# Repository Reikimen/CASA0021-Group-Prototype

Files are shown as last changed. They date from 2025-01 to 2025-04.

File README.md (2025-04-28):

# CASA0021: Group Prototype and Pitch 24/25

<div style="text-align: center;">
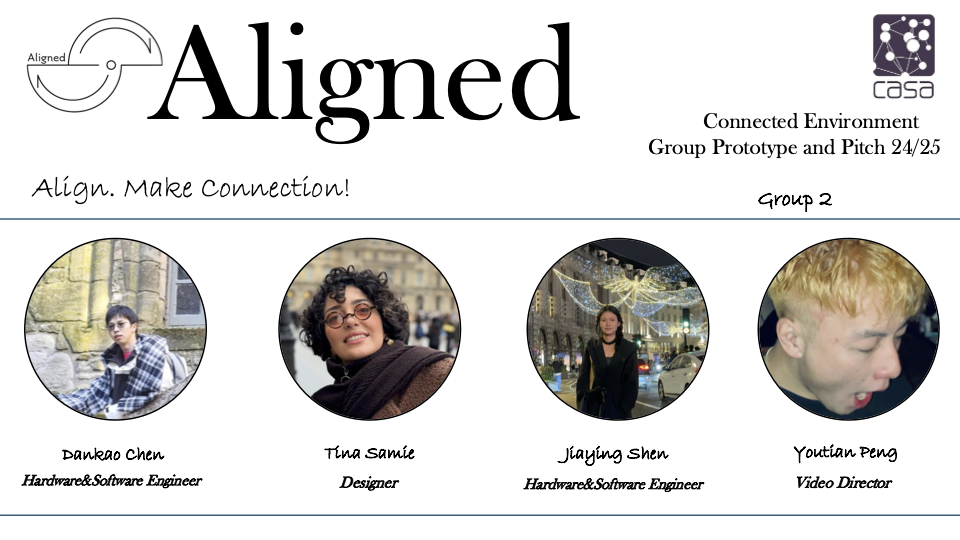
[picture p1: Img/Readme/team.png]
  
</div>

## 📌 Introduction

**Aligned** is a paired emotional communication device for people in long-distance relationships—whether romantic partners, family, or close friends. Instead of relying on texts or video calls, users connect by physically aligning their devices and sending emotions through light and vibration.

When one user rotates their device to face the direction of their partner and presses a button, a message is sent—but it will only be received when the other user also aligns in return. This two-way interaction adds a sense of presence and emotional balance that typical communication tools often lack.

**Aligned isn’t just a compass—it’s your emotional North Star.**

## 🌍 Why Aligned?

Staying connected across distances can be emotionally draining. Traditional tools like messaging and video calls are often screen-heavy, verbal, and fatiguing.

**Aligned** takes a different approach. It brings back the power of non-verbal connection—through direction, movement, and shared moments. Inspired by studies on the importance of physical cues in emotional bonding, Aligned helps users feel close, quietly and intentionally.

----

## 🎬 Demo Video

See how **Aligned** works in action:  
[▶️ Watch the short demo on YouTube](https://www.youtube.com/watch?v=aNNHWGniDm8)

---

## 🧭 How to Use Aligned

<table>
  <tr>
    <td align="center">
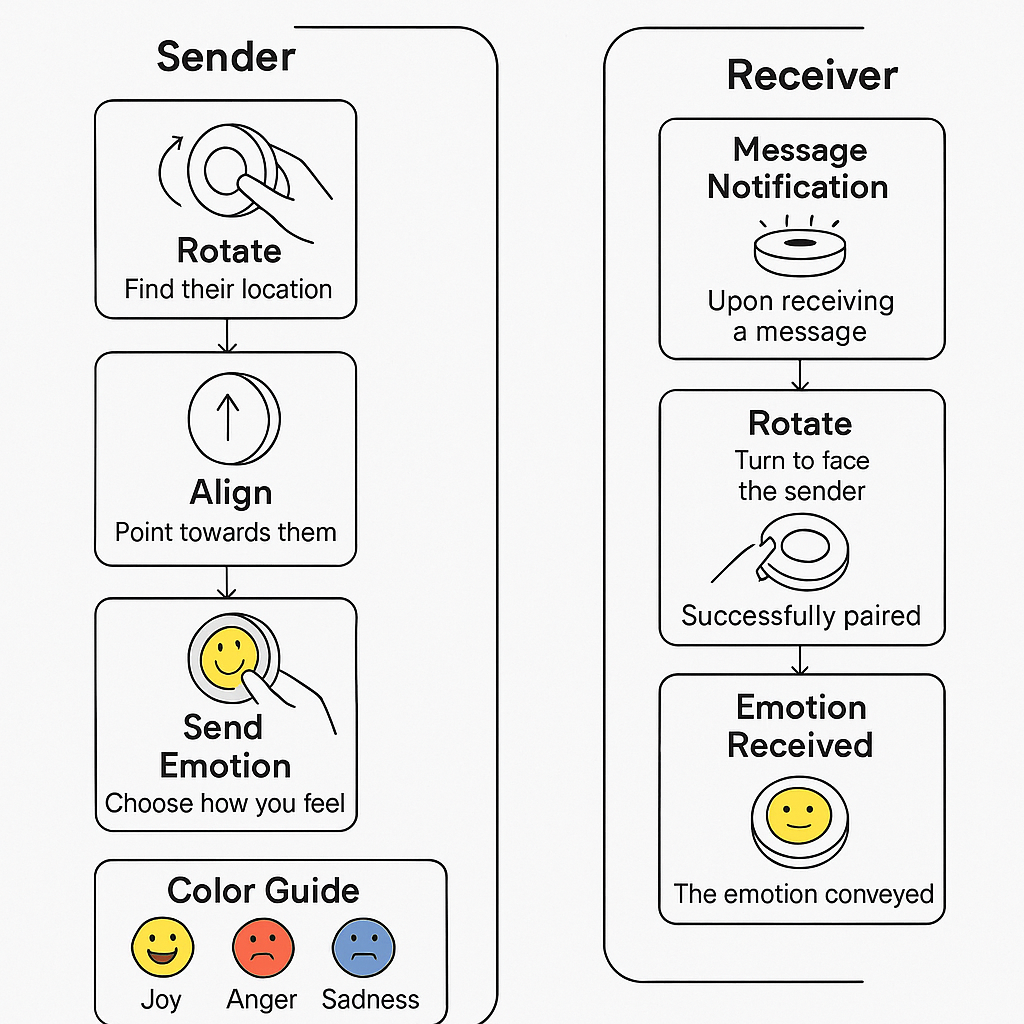
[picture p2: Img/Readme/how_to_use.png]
Flowchart 1
      
    </td>
    <td align="center">
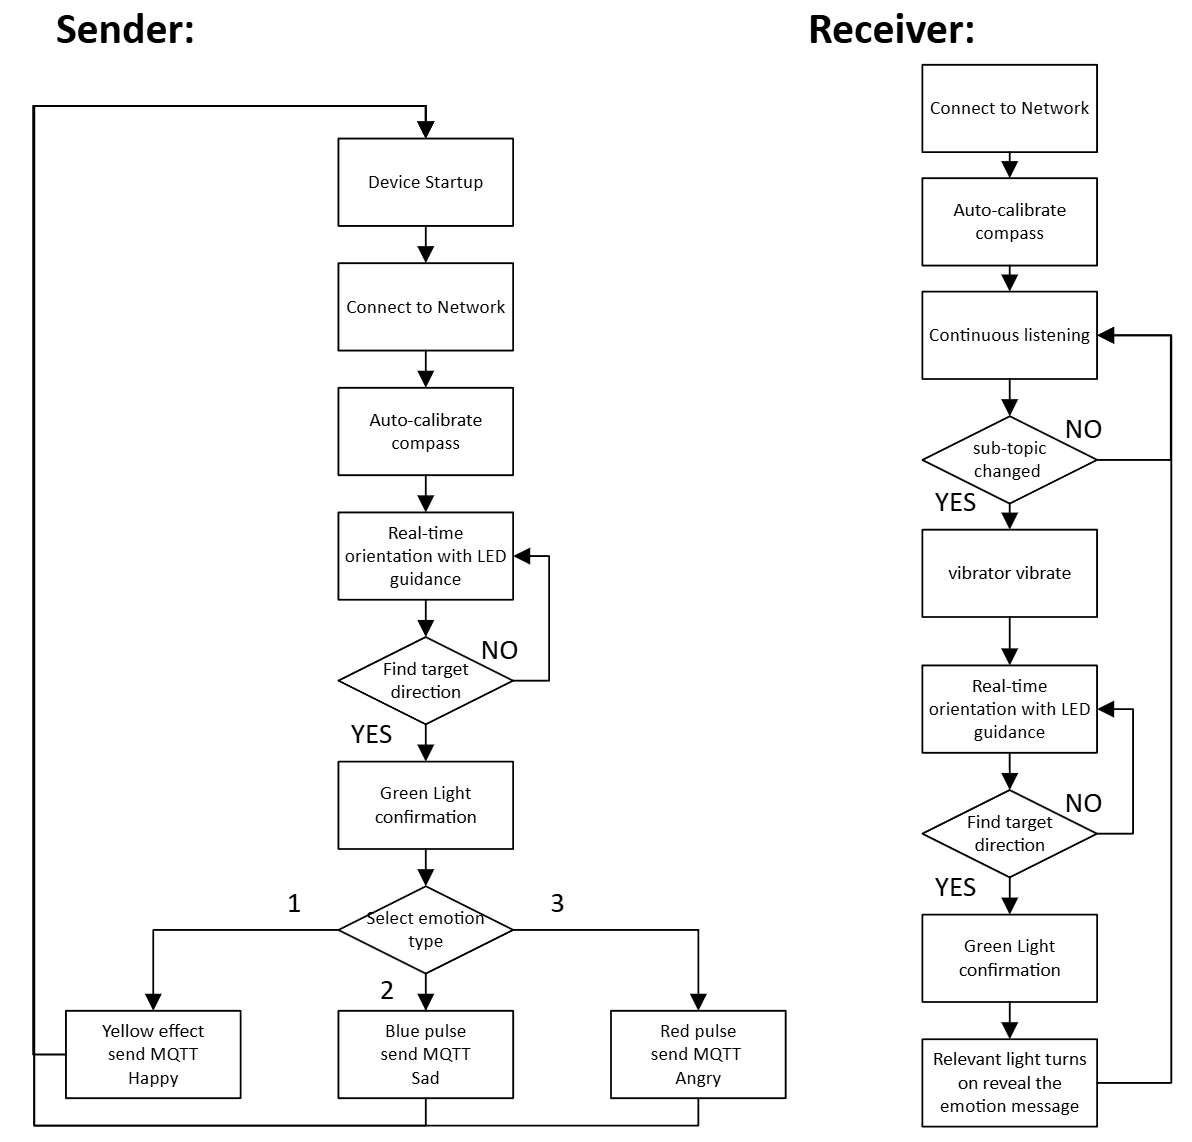
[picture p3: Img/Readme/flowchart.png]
Flowchart 2
      
    </td>
  </tr>
</table>

### Step 1: Power on the device  
Press the big start button. The device will automatically calibrate the built-in compass. 

### Step 2: Init the Product with our APP

On first use, you’ll be prompted to connect to your own Wi-Fi using your phone. 

<p align="center">
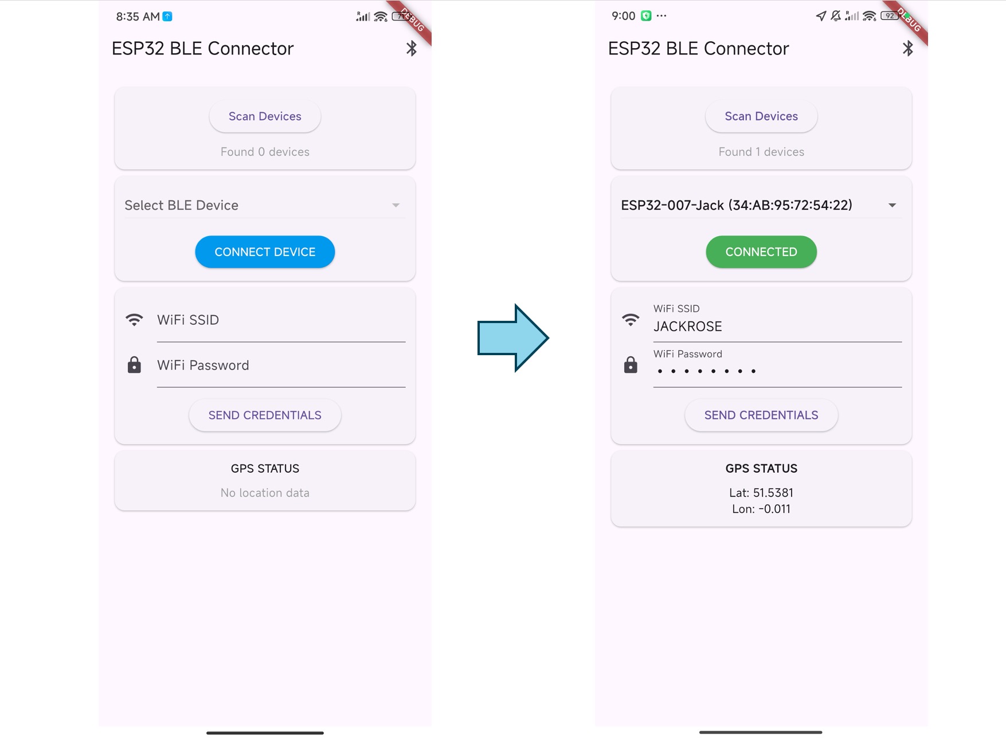
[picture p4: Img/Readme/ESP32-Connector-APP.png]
  
</p>

### Step 3: Enjoy Our "Alinged"

#### 💌 If you are the **Sender**:

1. **Rotate to find direction**  
   The device will help you locate the correct direction of your paired partner.  
   Once you are aligned, the LEDs will signal success.

2. **Choose how you feel**  
   Use the emotion buttons to send a feeling:
   - 🟡 Yellow → Happy  
   - 🔵 Blue → Sad  
   - 🔴 Red → Angry  

3. That’s it — your emotion is sent.  
   The other person can now receive it, but **only when they align with your direction**.

---

#### 📡 If you are the **Receiver**:

1. **Wait for a message**  
   When your partner sends a signal, your device enters **Seek Mode**. The LED ring starts showing **navigation indicators** to help you rotate and align:
   - 🟢 **Green navigation lights** → You’re pointing in the correct direction  
   - 🔴 **Red navigation lights** → You're off-target. Try turning in the opposite direction
   
2. Once aligned, the navigation lights will disappear, and the ring will glow in an **emotion color**—Yellow, Blue, or Red—depending on the feeling your partner sent.

---

#### 🛠️ Color Guide (LED Ring)

| Emotion | Color |
|---|---|
| 😊 Happy | 🟡 Yellow |
| 😢 Sad | 🔵 Blue |
| 😠 Angry | 🔴 Red |

---
### Precautions for use

To ensure optimal performance and longevity of your Aligned device, please observe the following precautions:

**Environmental Considerations**

- Do not place the device near strong magnetic fields as this may affect compass accuracy
- Ensure the device has sufficient space around it during rotation for accurate direction finding

**Battery and Power**
- Use only the provided USB cable for charging
- Do not charge the device while it is in use
- If the battery is completely depleted, charge for at least 10 minutes before attempting to power on

**Operational Safety**
- Do not disassemble or modify the device
- Keep the device away from children under 12 years old
- If the device becomes hot during use, turn it off immediately and allow it to cool

**Connectivity and Privacy**
- Ensure your Wi-Fi network has a stable internet connection
- Location permissions are only required during initial setup
- All emotional data is encrypted during transmission

**Maintenance**
- Keep the device away from water and excessive humidity
- Store the device in a cool, dry place when not in use
- Contact customer support if persistent issues occur

---
## Technical Architecture
### Software Design

The software architecture of the Aligned system is composed of two primary parts: the Android mobile application built using Flutter, and the firmware running on the ESP32 microcontroller via the Arduino platform. Together, these components enable seamless device initialization, connectivity, and core functionality.

#### Mobile Application (Flutter-based App)

The mobile application serves as the initial setup interface for the Aligned device, providing essential configuration data through Bluetooth Low Energy (BLE) connectivity.

The application establishes a connection using the service **UUID 0000ff01-0000-1000-8000-00805f9b34fb** and transmits data over two feature channels: the **WiFi credentials channel (UUID: 0000ff03-0000-1000-8000-00805f9b34fb)** is used to send the WiFi SSID and password, and the **GPS coordinates channel (UUID: 0000ff02-0000-1000-8000-00805f9b34fb)** is used to transmit location information. The app automatically obtains accurate location information from the phone's built-in GPS module and formats all the data into structured strings, such as SSID:xxx,PASS:xxx and LAT:xx.xxx,LON:xx.xxx, using UTF-8 encoding to ensure that the characters are transmitted correctly.

#### ESP32 Firmware (Arduino-based)

During the runtime phase, the device has multiple operating states: in normal mode, the device is idle and listens for messages; in seek mode, the user must align the device in the right direction to receive a message; in emotion send mode, the user rotates the device to find the direction of the partner and sends the emotion; and in message read mode, the device provides feedback when the direction is aligned.

<p align="center">
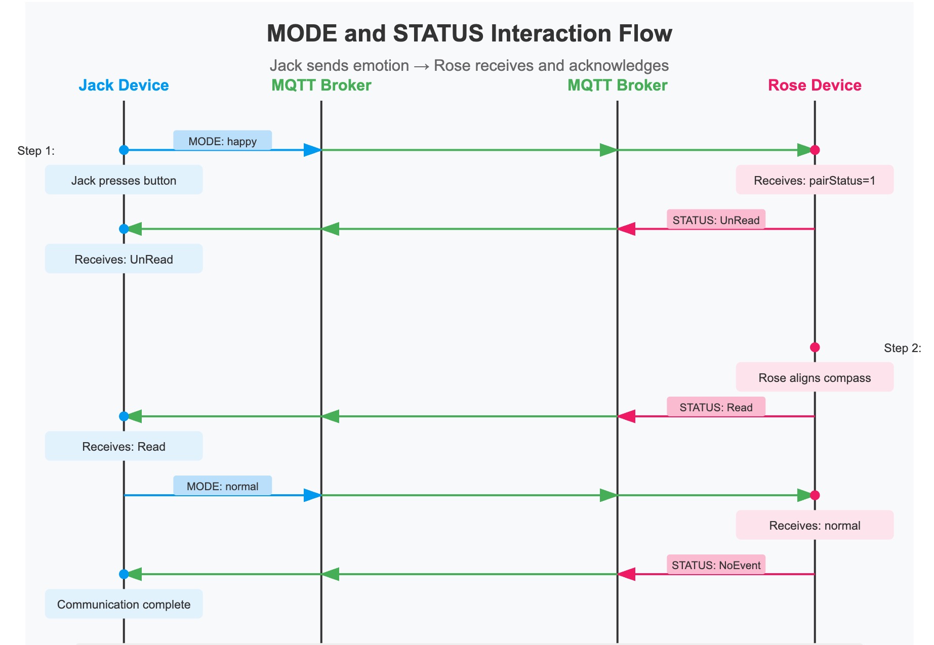
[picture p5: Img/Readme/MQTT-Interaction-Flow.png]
  
</p>

The Arduino firmware for this project adopts an innovative dual-equal role architecture design, where the device roles can be interchanged at any time; the sender and receiver are not fixed identities but are switched dynamically according to the current interaction needs. The firmware also achieves flexible configuration of multiple pairs of users and dual devices through a single code base, greatly reducing the maintenance cost and deployment complexity of the firmware. 

<p align="center">
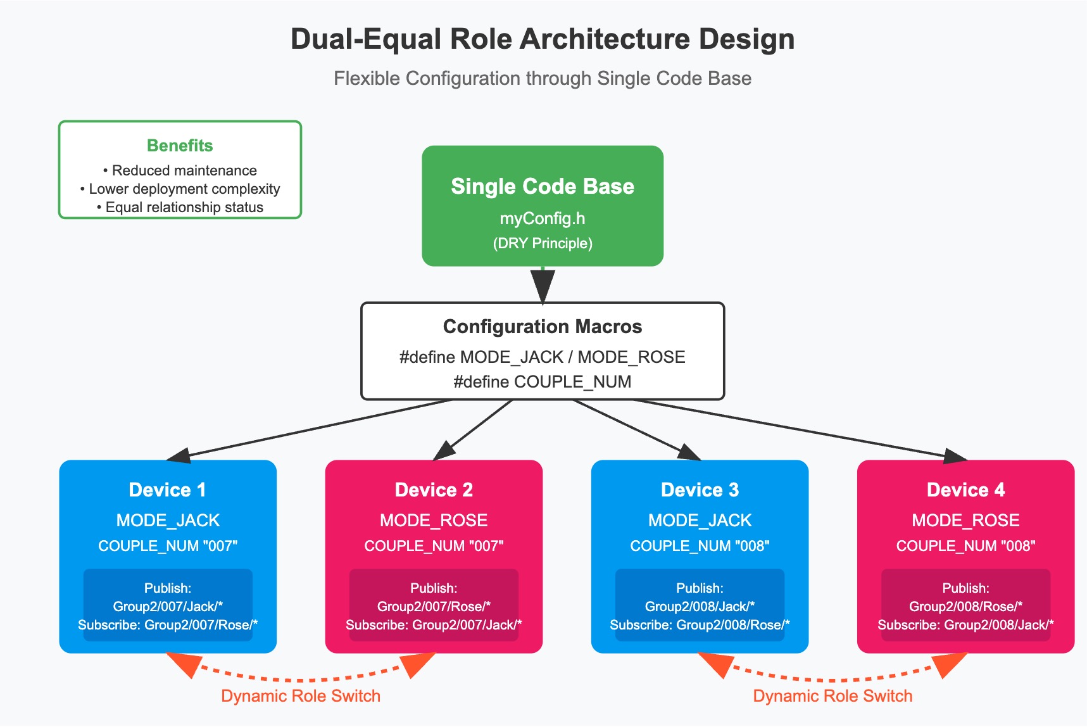
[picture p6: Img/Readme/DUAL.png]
  
</p>

By defining MODE\_JACK/MODE\_ROSE and COUPLE\_NUM macros in the header file, the system is able to automatically configure the corresponding device name and MQTT topic subscription publishing relationship without writing duplicate code. 

### Hardware Design
<p align="center">
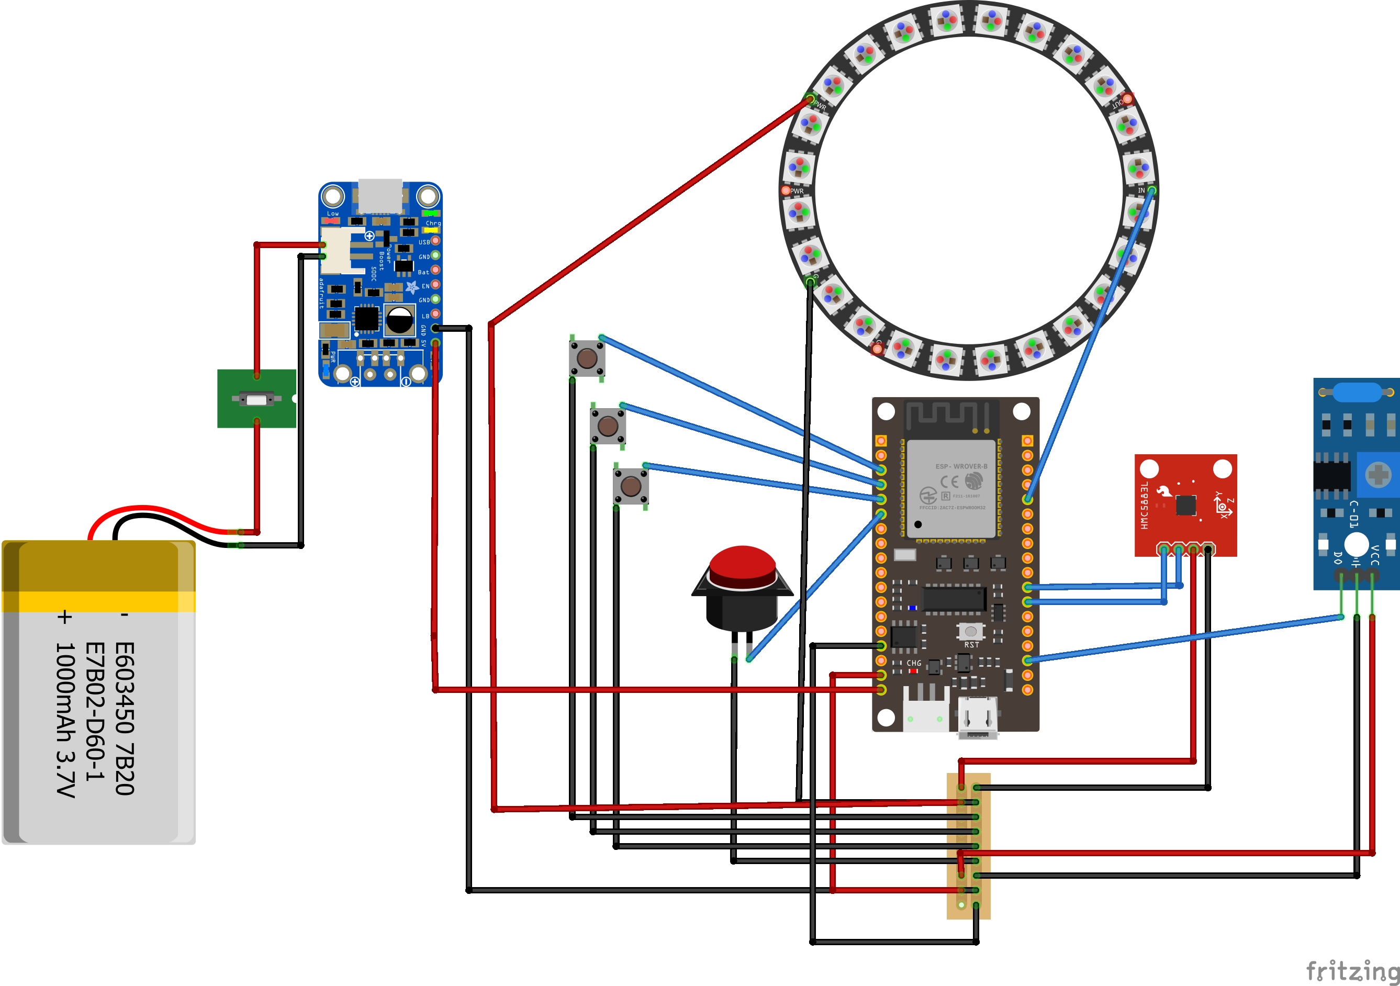
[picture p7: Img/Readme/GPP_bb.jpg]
  
</p>

| Component | Description |
|---|---|
| ESP8266 | Main MCU, handles logic and communication |
| NeoPixel Ring | RGB LED ring for visual feedback|
| Push Buttons | Three small tactile buttons for user input |
| Big Red Button | Primary start button |
| Switch Button | Control power on or off |
| HMC5883L | 3-axis digital compass for direction sensing |
| USB battery Module | LiPo battery charging and protection module |
| LiPo Battery (3.7V, 1000mAh) | Portable power source for the entire system |
| vibration | Provide hearable and touchable effect |
| MOSFET |  Provide higher power for vibration|

    pin4    --- button1(sad)
    pin18   --- button2(happy)
    pin19   --- button3(angry)
    pin23   --- start button4
    pin16   --- Motor
    pin2    --- LED ring
    D22     --- SCL
    D21     --- SDA
    VCC     --- 3.3V 
    GND     --- GND

----

### Reproducing the Enclosure & 3DPrint 

Aligned with the project's theme, the device was aimed to be carried by the user as a small, handheld device. In this regard, one of the main aspects of this project was the enclosure's design. The design of the enclosure follows three primary principles:

1. **Compact and Portable:** Designed to be small and pocket-sized for comfortable handheld use, the device's wireless capabilities ensure convenience and ease of transport.
2. **User-Friendly:** Intuitive operation is paramount, with straightforward usage and clear, easily interpretable signs and colors.
3. **Aesthetic Appeal:** A visually pleasing design that is sleek and customizable to suit individual preferences.

<p align="center">
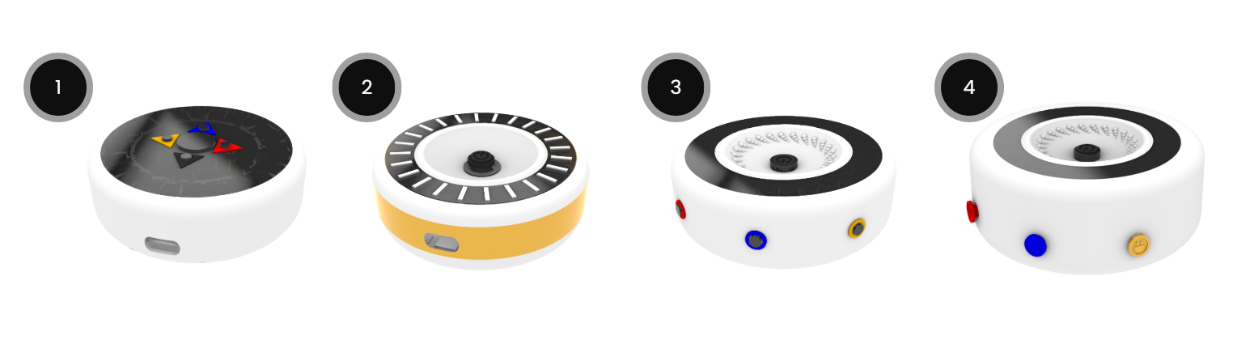
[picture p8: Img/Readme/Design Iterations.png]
  
</p>

## How to Dowload the files

### 3D model

You can find different versions of the model in the 3D model folder. Most of the modeling was done in Rhino 8, therefore the best platform to open this file is using Rhino, however the files could be imported to anyother modleing software that compatible with the file format. The G-code for the 3d printing is also available with the settings included in the name. 
There is also another file for lasercutting the top LED ring diffuser from a 3mm black acrylic sheet and the buttons with respective colours for each emotion. 

<p align="center">
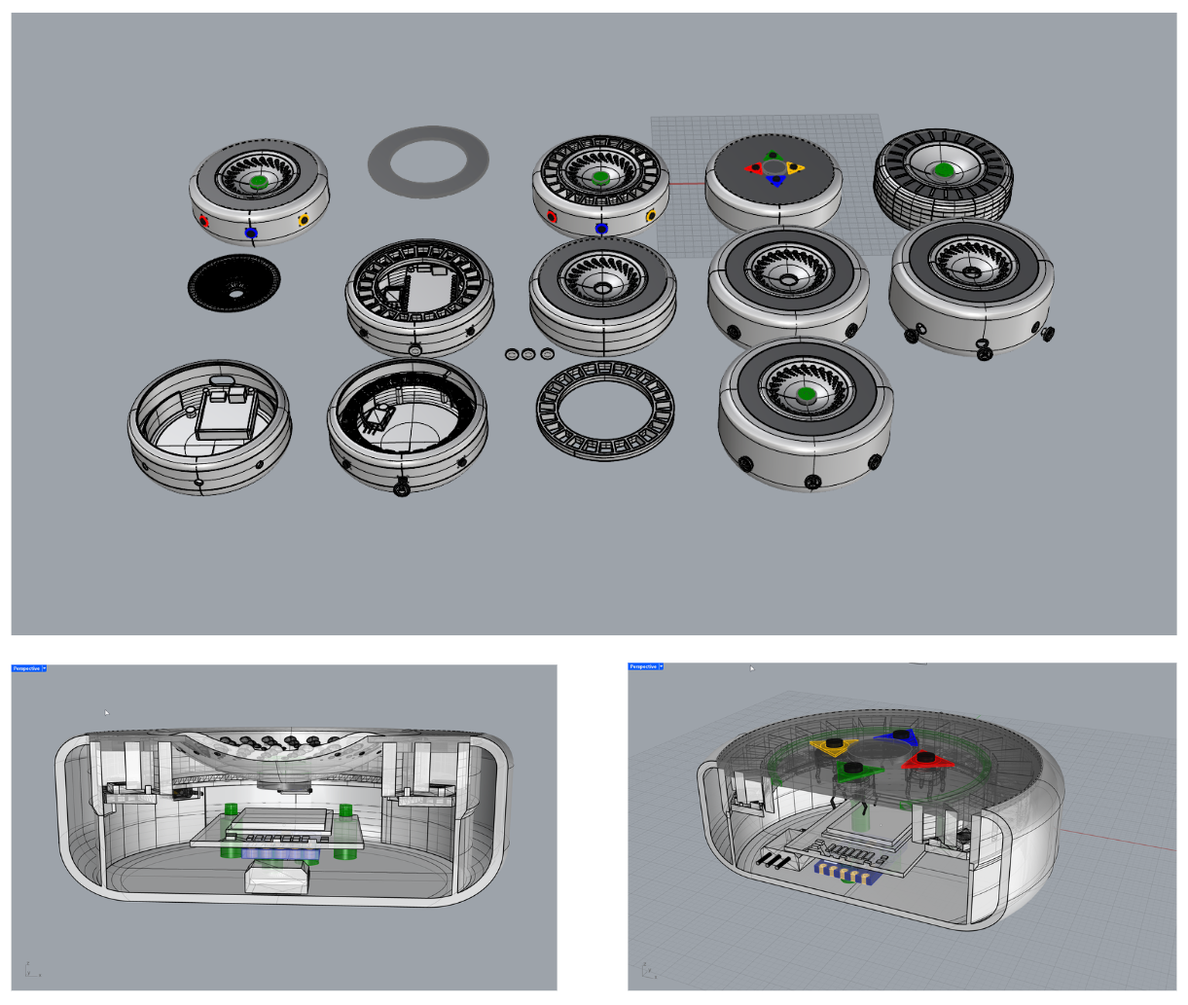
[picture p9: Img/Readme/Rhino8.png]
  
</p>
The device's compact size presented numerous challenges for designing the enclosure. Some of the challenges overcome in the prototyping process were efficiently arranging all components, including the battery with its charger module, in a small space and ensuring that all components were accessible. 

### Arduino

The root is ```/main-Program/main_program_GPP_combine_v4```

### Flutter

The root is ```/flutter_app```

## Reference:

1. [https://github.com/troelssiggaard/ESP32-fritzing-module](https://forum.fritzing.org/t/esp-wroom-32d-firebeetle/13869/5)

2. https://github.com/adafruit/Fritzing-Library/blob/master/parts/retired/Neopixel%2024%20Ring.fzpz

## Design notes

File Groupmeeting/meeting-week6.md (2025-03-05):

---
typora-root-url: ../.
---

## Meeting Information
- **Topic**: Enclosure Design, Circuit Design,Vedio Production
- **Date**:  2025/03/11
- **Location**:  UCL EAST OPS
- **Attendees**:  Everyone in CASA0021 Group 2
- **Note-taker**:  YouTian

---

## Agenda
1.  Current work demo
2.  Vedio production dicussion
3.  Following work

---

## Discussion Notes

### 1. Topic 1
- **Discussion**:  Enclosure Design
- **Decisions/Actions**: we designed three version, and based on voted result we choose the second version as our product's design.
- **Deadline**:  ~

### 2. Topic 2
- **Discussion**:  Vedio production
- **Decisions/Actions**:  the script and sceen design is finished. The vedio making is on process.
- **Deadline**: ~

### 3. Topic 3
- **Discussion**:  Circuit Design
- **Decisions/Actions**: The functionalities design are finished, but there're some issues with the size now
- **Deadline**:  ~

---

## Action Items
| Task Description | Owner | Deadline | Status |
| --- | ----- | --- | --- |
| Device Integration | Dankao+Flora | 2025/03/11 | on going |
| Enclosure Design | Tina | - | finished |
| Vedio Making | YouTian | ~2025/02/17 ~| on going |

---

## Other Notes
-  
-  

---

**Remarks**:

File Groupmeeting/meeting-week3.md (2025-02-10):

---
typora-root-url: ../.
---

## Meeting Information
- **Topic**: Vedio dicussion and following actions
- **Date**:  2025/02/10
- **Location**:  UCL EAST OPS
- **Attendees**:  Everyone in CASA0021 Group 2
- **Note-taker**:  YouTian

---

## Agenda
1.  Current work demo
2.  Vedio production dicussion
3.  Following work

---

## Discussion Notes

### 1. Topic 1
- **Discussion**:  Current work demo
- **Decisions/Actions**: app developed, fetch the location data successfully, might give up the GPS module
- **Deadline**:  -

### 2. Topic 2
- **Discussion**:  vedio production
- **Decisions/Actions**:  got some ideas, but need further discussion with script and scene design and so on
- **Deadline**:  2025/02/17

### 3. Topic 3
- **Discussion**:  lighting system design, device angle match system design and enclosure design need to begin
- **Decisions/Actions**:  -
- **Deadline**:  not very clear(2025/02/17 for update)

---

## Action Items
| Task Description | Owner | Deadline | Status |
| --- | ----- | --- | --- |
| Device Angle Matching System | Dankao+YouTian | 2025/02/17 | on going |
| Enclosure Design | Tina&Flora(JiaYing) | - | on going |
| Vedio Script | YouTian | 2025/02/17 | on going |

---

## Other Notes
-  
-  

---

**Remarks**:

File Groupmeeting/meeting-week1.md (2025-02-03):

---
typora-root-url: ../.
---

## Meeting Information
- **Topic**:  Popotype Design
- **Date**:  27/1/2025
- **Location**:  UCL EAST OPS
- **Attendees**:  Everyone in CASA0021 Group 2
- **Note-taker**:  Dankao

---

## Agenda
1.  Shape design and user interaction
1.  Idea of "linked"
1.  Purchasing list

---

## Discussion Notes

### 1. Topic 1: Shape design and user interaction
- **Discussion**:  

  - **UX Idea 1:** Cosmetic mirror opening and closing

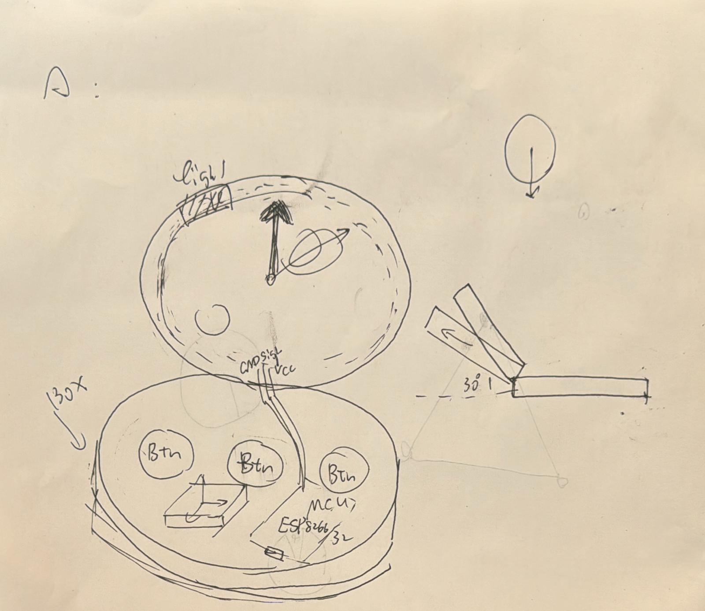
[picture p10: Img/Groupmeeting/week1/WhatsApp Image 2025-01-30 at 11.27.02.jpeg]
WhatsApp Image 2025-01-30 at 11.27.02
    

  - **UX Idea 2:** The side is attached to the LED light belt, through which the direction is indicated.

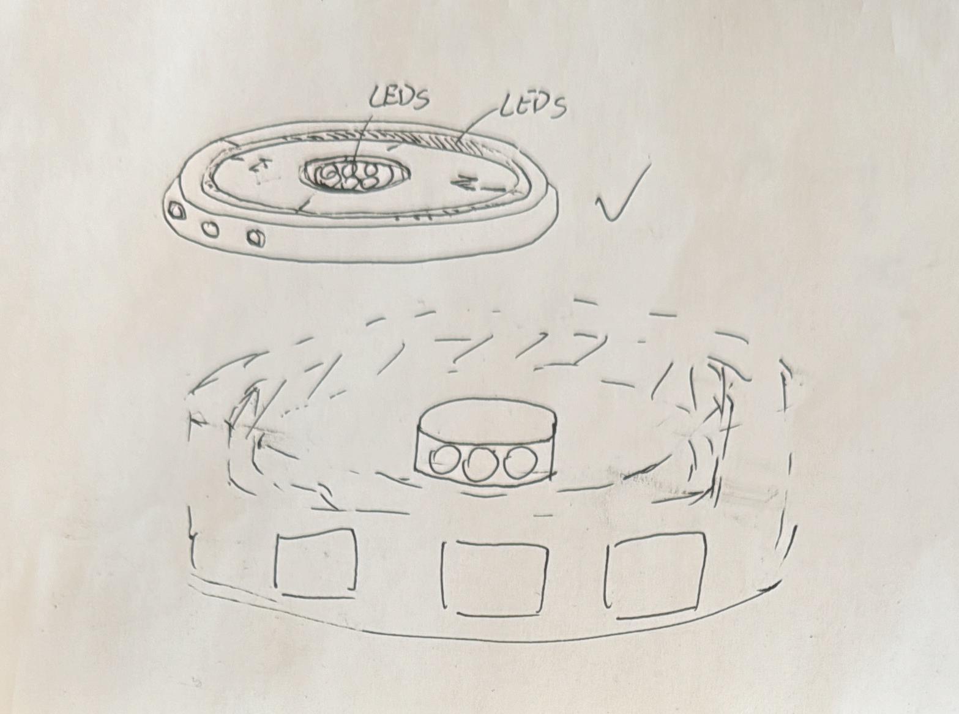
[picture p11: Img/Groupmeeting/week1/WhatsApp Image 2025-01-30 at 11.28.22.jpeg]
WhatsApp Image 2025-01-30 at 11.28.22
    
    
  - **UX Idea 3:** On the basis of Idea2, the fixed pointer is changed to the luminous pointer
  
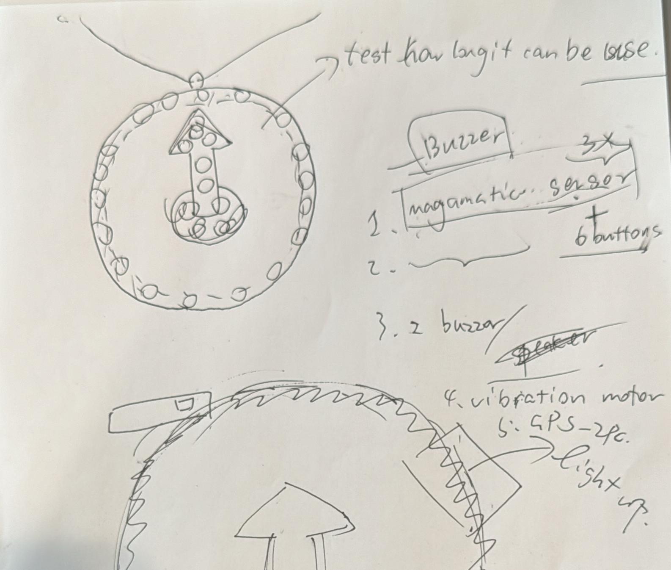
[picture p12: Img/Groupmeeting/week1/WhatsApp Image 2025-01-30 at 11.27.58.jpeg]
WhatsApp Image 2025-01-30 at 11.27.58
    

- **Decisions/Actions**:  UX Idea 3 was chose.

- **Deadline**:  /

### 2. Topic 2: Idea of "linked"
- **Discussion**: 

  - **Linked Idea 1:** 

    The original idea is - Connected to each other in a physical sense, connected when face to face. Therefore GPS had to be used to locate the devices to ensure a face-to-face connection.

    **Issues:**

    1. GPS module consumes more energy
    2. GPS modules are expensive, resulting in higher equipment production costs

    **Solutions:**

    1. Each time the device is switched on, the GPS is used to obtain location information (for about 10s), and is switched off as soon as the location information is obtained, unless the user performs a repositioning operation while using the device, in which case the GPS is switched on for a short period of time, obtains the information, and is switched off automatically.
    2. The Second solution is to use a mobile app that retrieves location details from the personal smartphone of the user and send it to the device to be used in the calculations. This would remove the need for a built-in GPS which automaticaly solves the problem of powering and cost of implementing a GPS module within the device.

  - **Linked Idea 2:** 

    Suppose there are two users, Jack and Rose, who are lovers in a long-distance relationship. Suppose Rose, at a certain point in time, feels sad because her job is not going well. So she switches on our compass, and after switching on the device, she rotates it at a particular angle relative to when the device was switched on and presses the ‘Stressed Out’ button, while Jack receives a vibration from the compass at the same time 📳. Jack, after switching on the device, rotates the angle at which Rose pressed the button, at which point the light band on the compass flashes and vibrates slightly, picking up Rose's mood message.
    
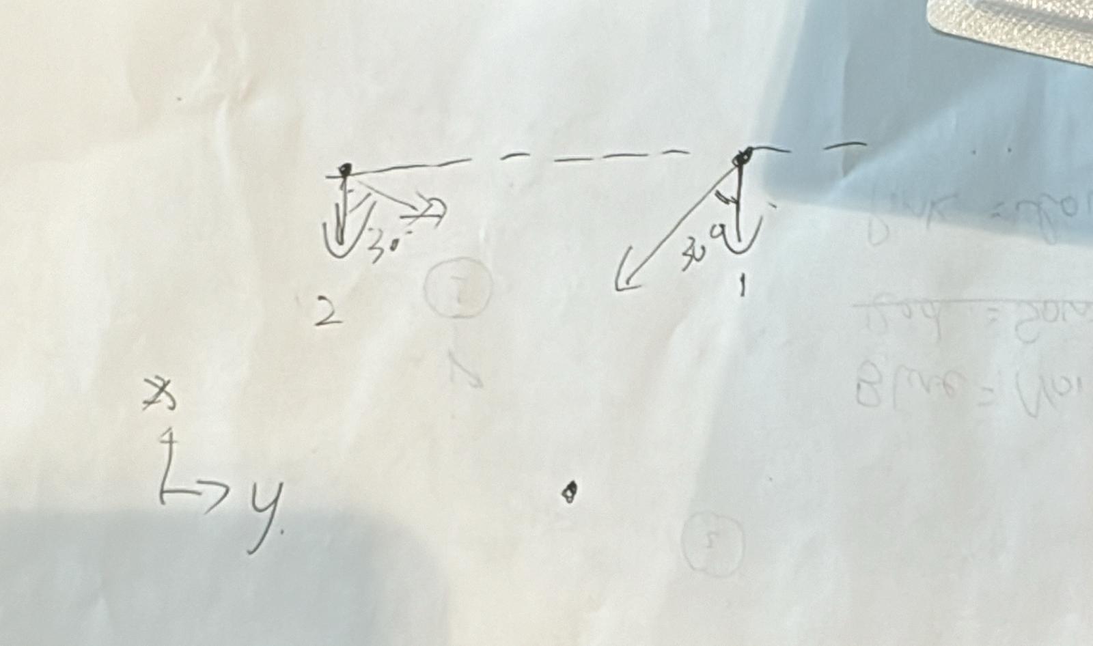
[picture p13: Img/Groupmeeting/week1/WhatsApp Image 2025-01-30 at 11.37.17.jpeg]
WhatsApp Image 2025-01-30 at 11.37.17
    

- **Decisions/Actions**:  

  Not decided yet

- **Deadline**:  /

### 3. Topic 3: Purchasing list
- **Discussion**:  According to Idea 3

- **Decisions/Actions**: 

  Here is the Bom Chart

  | ID | Component      | Type       | Num | Link        |
  |------|----------------|---------------|------|------------|
  | 1    | Magnetometer Sensor| HMC5883L | 3    | [HMC5883L](https://www.amazon.co.uk/DAOKAI-Three-axis-magnetic-QMC5883L-Magnetometer/dp/B0CD77DN87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)     |
  | 2    | Push Button    | 12pcs 12mm     | 1    |[Push Button](https://www.amazon.co.uk/gp/product/B07XQSBW7Q/ref=sw_img_1?smid=A1DBC97EH2O973&th=1)      |
  | 3    | 3PCS Vibration Motor | M20 Mini | 1   | [M20 Mini](https://www.amazon.co.uk/Vibration-Electric-Vibrating-Eccentric-Instrument/dp/B07WP2PGBW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) |
  | 4    | 2PCS GPS Module | Aideepen | 1    | [GPS Module](https://www.amazon.co.uk/Aideepen-GY-GPS6MV2-Position-Antenna-Controller/dp/B08CZSL193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)   |

  Subtotal (6 items): **£53.03**

- **Deadline**: /

---

## Action Items
| Task Description | Owner | Deadline  | Status |
| --- | --- | --- | --- |
| Shape design and user interaction | Group 6 | / | On going |
| Purchasing items | Dankao  | 30/1/2025 | On going |
| Decision of Linking Idea (ask tutor) | Group 6 | / | Not Start Yet |

---

## Other Notes (left Questions)
-  Decision of Linking Idea
-  The manner in which a user enters information with the device and how much information is exchanged with another user

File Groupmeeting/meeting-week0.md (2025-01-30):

---
typora-root-url: ../.
---

## Meeting Information
- **Topic**:  Came up with the idea of how to co-operate
- **Date**:  Before week1
- **Location**:  UCL EAST OPS
- **Attendees**:  Everyone in CASA0021 Group 2
- **Note-taker**:  Youtian / Dankao

---

## Agenda
1.  Appromix Gannt Chart (Task Allocation)
3.  Project Topic

---

## Discussion Notes

### 1. Topic 1: Appromix Gannt Chart (Task Allocation)
- **Discussion**:  

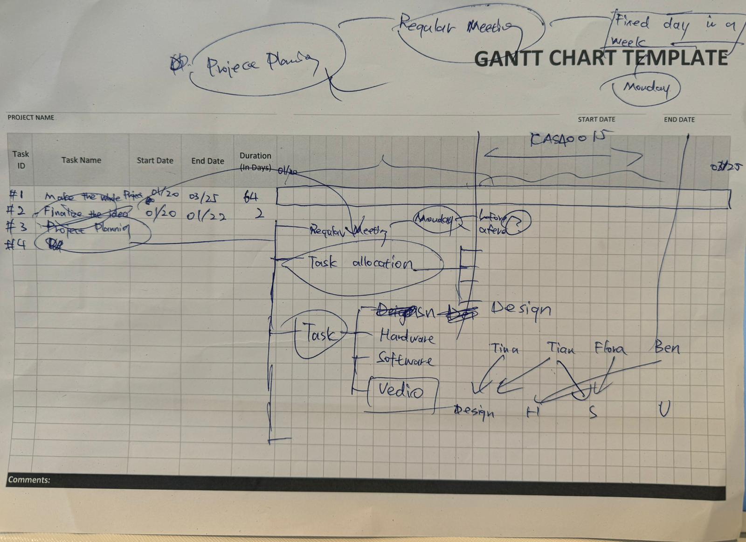
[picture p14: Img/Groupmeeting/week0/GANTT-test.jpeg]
GANTT-test
  

- **Decisions/Actions**:  Need futher task allocation after the topic is decided

- **Deadline**:  /

### 2. Topic 2: Project Topic
- **Discussion**:  

  A lot of ieads... All oral discussion without recording, so hard to track.

- **Decisions/Actions**:  Group 2 would build a Slide together to intro the project to the class

- **Deadline**: 
24/1/2025 for final decision of the project idea. Finish the slide before 27/1/2025.

---

## Action Items
| Task Description | Owner | Deadline  | Status |
| --- | --- | --- | --- |
| Topic decision | Group 2 | 24/1/2025 | On going |
| Make the slide | Group 2 | 27/1/2025 | On going |

---

## Other Notes
-  /
-  /

---

**Remarks**:  

Our group is gonna to have a regular meeting on Monday, after the class.

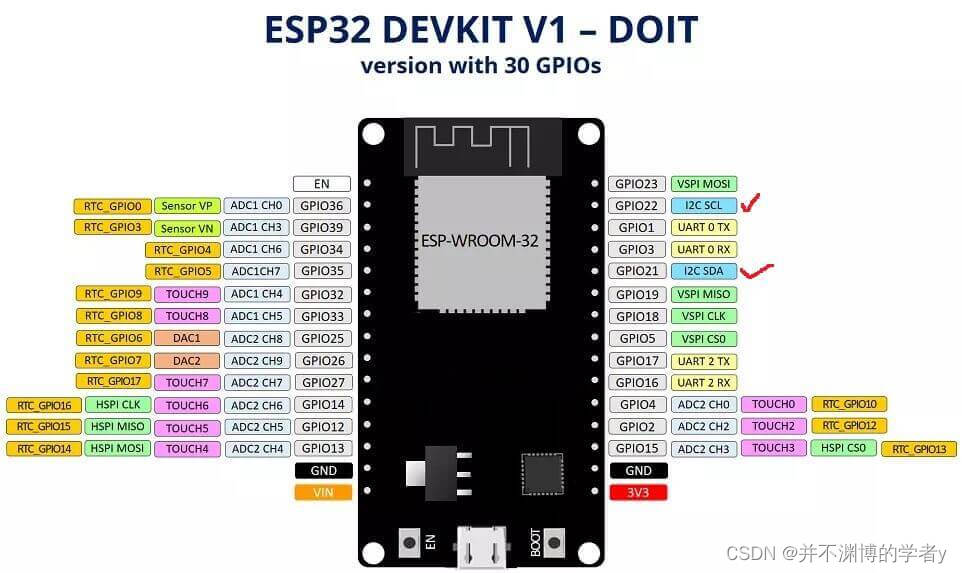
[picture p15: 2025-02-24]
Components/ESP32-Devkit-Pinout.jpeg

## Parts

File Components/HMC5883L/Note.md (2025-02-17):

**required library: QMC5883LCompass.h**

**resources:**
https://github.com/mprograms/QMC5883LCompass

Calibration test result:
22:27:00.754 -> compass.setCalibrationOffsets(-565.00, -1193.00, 712.00);
22:27:00.819 -> compass.setCalibrationScales(0.93, 0.90, 1.24);

22:31:27.016 -> compass.setCalibrationOffsets(-720.00, -1092.00, 577.00);
22:31:27.081 -> compass.setCalibrationScales(0.90, 0.93, 1.23);

22:32:34.561 -> compass.setCalibrationOffsets(-512.00, -1101.00, 549.00);
22:32:34.629 -> compass.setCalibrationScales(1.10, 0.95, 0.96);

22:34:30.083 -> compass.setCalibrationOffsets(-589.00, -1182.00, 912.00);
22:34:30.147 -> compass.setCalibrationScales(1.25, 0.81, 1.04);

22:35:08.684 -> compass.setCalibrationOffsets(-708.00, -1408.00, 895.00);
22:35:08.716 -> compass.setCalibrationScales(1.33, 0.73, 1.14);

**direction_code notice:**
Azimuth=0°, pointer: x points to North

**ESP32:** 
SCL -- D22
SDA -- D21
VCC -- 3.3V
GND -- GND

Board manager URL: https://dl.espressif.com/dl/package_esp32_index.json

**ESP8266:**
SCL -- D1
SDA -- D2
VCC -- 3.3V
GND -- GND

Board manager URL: https://arduino.esp8266.com/stable/package_esp8266com_index.json

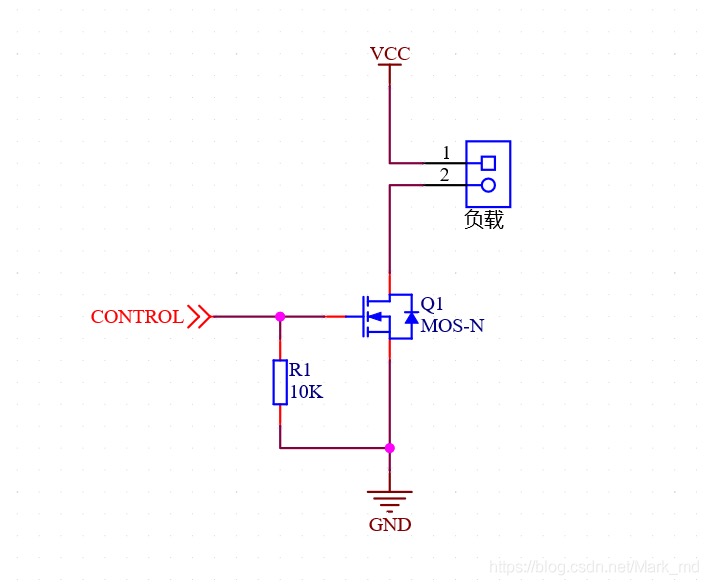
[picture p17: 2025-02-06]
Components/vibration-motor-M20/NMOSFET.jpg

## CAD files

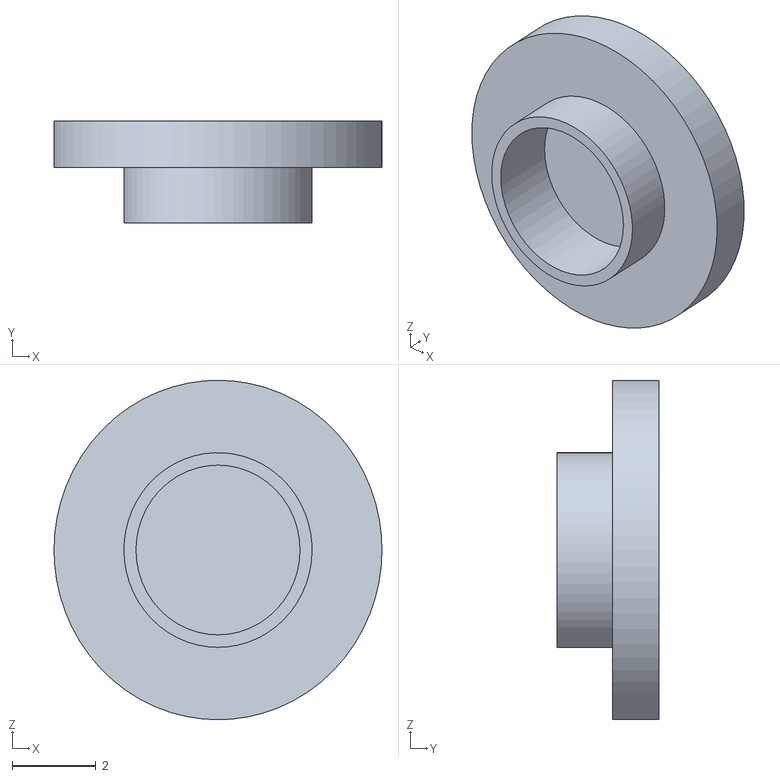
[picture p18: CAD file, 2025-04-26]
3D_Model/buttonCapHolderV3.stl
7.81 x 2.42 x 8.08

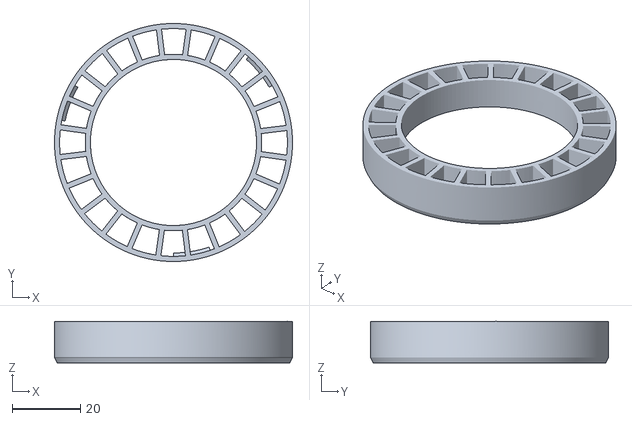
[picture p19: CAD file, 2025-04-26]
3D_Model/LEDholder.stl
69.5 x 69.5 x 12.1

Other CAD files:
3D_Model/V5.gcode.3mf

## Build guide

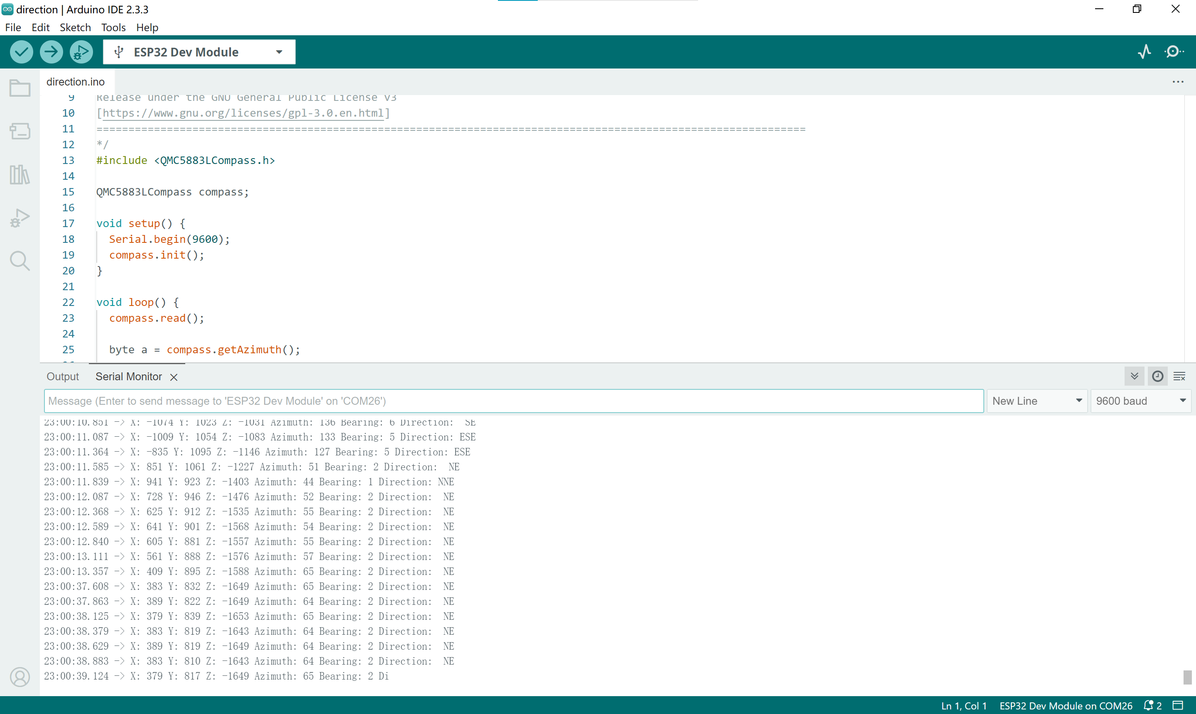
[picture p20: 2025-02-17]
Components/HMC5883L/Img/serialPrint.png

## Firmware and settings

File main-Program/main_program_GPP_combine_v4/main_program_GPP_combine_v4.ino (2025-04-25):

#include <WiFi.h>
#include <PubSubClient.h>
#include <BLEDevice.h>
#include <BLEUtils.h>
#include <BLEServer.h>
#include <BLE2902.h>
#include <Preferences.h>
#include <QMC5883LCompass.h>
#include <math.h>
#include <Adafruit_NeoPixel.h>
#include <esp_sleep.h>  // low power mode lib

#include "arduino_secrets.h"
#include "myConfig.h"
#include "myCompass.h"
#include "myLEDandBtns.h"

// ===== Main Program =====c:\Users\JiaYing\Downloads\arduino_secrets.h
void setup() {
  Serial.begin(115200);
  calibrateCompass(); // 每次启动时进行校准
  // waitForNorthCalibration();  // First detect azimuth == 0 before proceeding 
  Compass_BLE_WiFi_MQTT_init();
  init_LEDandBtn();
}

void loop() {
  // All operations of BLE, Wi-Fi & GPS info update are handled by callbacks
  // Check MQTT connections
  reconnectMQTT();// 如果Wi-Fi没连接就先连接Wi-Fi，没连接MQTT就连接MQTT
  
  // Keep MQTT client background tasks
  client.loop();
  
  // Allways updating the GPS Info
  if (loactionCount >= 0){
    loactionCount--;
  }else{
    loactionCount = 200; // 除了第一次是开启后5s发送，之后都是20s发送一次，减少播客占用
    sendmqtt_location(); // the function for sending MQTT GPS message based on the mode you set in mgConfig.h
  }

  // 按下某个按钮触发某个心情事件，发送MQTT
  // 以下为每30s模拟按下一次按钮
  // if (emotionDebugCount >= 0){
  //   emotionDebugCount--;
  // }else{
  //   emotionDebugCount = 300;
  //   sendmqtt_angry(); // the function for sending MQTT message based on the mode you set in mgConfig.h
  // }
  // 以下为各个心情事件的函数名称
  // sendmqtt_happy();
  // sendmqtt_sad();
  // sendmqtt_angry();
  // sendmqtt_normal();
  // delay(500);

  if (startPressed){
    startPressed = false;
    foundOrNot = false;
    RightDirOrNot = false;
    startPressCount++;
    lightUpPixels(0, 23, 255, 255, 255);  
    Serial.println("START: Lights ON");
    digitalWrite(MOTOR_PIN, HIGH);
    delay(300);
    digitalWrite(MOTOR_PIN, LOW);
  }

  if (!foundOrNot){
      // waitForNorthCalibration();  // First detect azimuth == 0 before proceeding
      if (!RightDirOrNot){
        double bearing = calculateBearing(storedLAT, storedLON, grabedLAT, grabedLON);

        compass.read();
        
        int azimuth = compass.getAzimuth();
        char myArray[3];
        compass.getDirection(myArray, azimuth);

        Serial.print("Azimuth: ");
        Serial.print(azimuth);
        Serial.print(" | Target: ");
        Serial.print(bearing);
        Serial.print(" | Direction: ");
        Serial.print(myArray[0]);
        Serial.print(myArray[1]);
        Serial.print(myArray[2]);
        Serial.println();

        // Check if azimuth is within ±5 degrees of the target
        if (isTargetAzimuthReached(azimuth, bearing)) {
          // 如果对准了做以下动作
          lightUpPixels(0, 23, 0, 255, 0);
          // digitalWrite(MOTOR_PIN, HIGH);
          delay(500);
          // digitalWrite(MOTOR_PIN, LOW);
          pixels.clear();
          pixels.show();
          // break;  // Exit loop
          Serial.println("Send your emotion「LED」, 1 for happy, 2 for sad, 3 for angry");
          RightDirOrNot = true;
          sendOrNot = false;
        }
        else {
          updateNeoPixels(azimuth, bearing);
        }
      }

      if (!sendOrNot) {
        if (button1Pressed) {
          button1Pressed = false;
          Serial.println("SAD");
          sendmqtt_sad();
          lightUpPixels(0, 23, 0, 0, 255);  
          // digitalWrite(MOTOR_PIN, HIGH);
          delay(300);
          // digitalWrite(MOTOR_PIN, LOW);
          pixels.clear();
          pixels.show();
          sendOrNot = true;
          foundOrNot = true;
          startPressed = false;
        } else if (button2Pressed) {
          button2Pressed = false;
          //lightUpPixels(12, 16, 255, 255, 0);  
          Serial.println("HAPPY");
          sendmqtt_happy();
          // lightUpRainbow(); 
          lightUpPixels(0, 23, 255, 255, 0);  
          // digitalWrite(MOTOR_PIN, HIGH);
          delay(300);
          // digitalWrite(MOTOR_PIN, LOW);
          pixels.clear();
          pixels.show();
          sendOrNot = true;
          foundOrNot = true;
          startPressed = false;
        } else if (button3Pressed) {
          button3Pressed = false;
          //lightUpPixels(18, 24, 255, 255, 0);  
          Serial.println("ANGRY");
          sendmqtt_angry();
          lightUpPixels(0, 23, 255, 0, 0);  
          // digitalWrite(MOTOR_PIN, HIGH);
          delay(300);
          // digitalWrite(MOTOR_PIN, LOW);
          pixels.clear();
          pixels.show();
          sendOrNot = true;
          foundOrNot = true;
          startPressed = false;
        }
      }
    }
    
    // else if (startPressCount == 2){
    //   Serial.println("Entering Deep Sleep...");
    //   delay(500); 
    //   enterDeepSleep(); 
    //   startPressCount = 0;
    // }

  if (!ReadOrNot){
    motorCount++;
    if (motorCount <= 30){
      digitalWrite(MOTOR_PIN, HIGH);
    }
    else if (motorCount <= 60){
      digitalWrite(MOTOR_PIN, LOW);
    }
    else{
      motorCount = 0;
    }
  }
  

  if (!ReadOrNot){ // 如果还没有阅读对面的情绪信息，需要一直旋转罗盘直到对准对面
    // Serial.println("Pls use the compase to find the dir.");

    double bearing = calculateBearing(storedLAT, storedLON, grabedLAT, grabedLON);

    compass.read();
      
    int azimuth = compass.getAzimuth();
    char myArray[3];
    compass.getDirection(myArray, azimuth);

    Serial.print("Azimuth: ");
    Serial.print(azimuth);
    Serial.print(" | Target: ");
    Serial.print(bearing);
    Serial.print(" | Direction: ");
    Serial.print(myArray[0]);
    Serial.print(myArray[1]);
    Serial.print(myArray[2]);
    Serial.println();

    // Check if azimuth is within ±5 degrees of the target
    if (isTargetAzimuthReached(azimuth, bearing)) {
      // 再根据 pairStatus for normal, 1 for happy, 2 for sad, 3 for angry，显示对应的颜色
      Serial.println("Indicate your pair's emotion「LED」, 1 for happy, 2 for sad, 3 for angry");
      if (pairStatus==1){
        // lightUpRainbow();
        lightUpPixels(0, 23, 255, 255, 0);  
      }
      else if (pairStatus==2){
        lightUpPixels(0, 23, 0, 0, 255);
      }
      else if (pairStatus==3){
        lightUpPixels(0, 23, 255, 0, 0);
      }
      else{
        // 一般没有其他情况，如有，则检查MQTT部分代码
      }
      // regular viberate
      // lightUpPixels(0, 23, 100, 0, 100);
      digitalWrite(MOTOR_PIN, HIGH);
      delay(500);
      digitalWrite(MOTOR_PIN, LOW);
      delay(500);
      digitalWrite(MOTOR_PIN, HIGH);
      delay(500);
      digitalWrite(MOTOR_PIN, LOW);
      delay(500);
      digitalWrite(MOTOR_PIN, HIGH);
      delay(500);
      digitalWrite(MOTOR_PIN, LOW);
      delay(500);
      digitalWrite(MOTOR_PIN, HIGH);
      delay(500);
      digitalWrite(MOTOR_PIN, LOW);
      delay(500);
      digitalWrite(MOTOR_PIN, HIGH);
      delay(500);
      digitalWrite(MOTOR_PIN, LOW);
      delay(500);
      digitalWrite(MOTOR_PIN, HIGH);
      delay(500);
      digitalWrite(MOTOR_PIN, LOW);
      delay(500);
      // 如果对准了做以下动作
      sendmqtt_STATUS_Read(); //发布：已经收到对方情绪
      ReadOrNot = true; // 将全局变量阅读状态改为已读

      pixels.clear();
      pixels.show();
    }
    else {
      // 如果没有对准，使用灯光指示
      updateNeoPixels(azimuth, bearing);
    }
  }

  delay(100);  // Loop every 0.1 seconds
}

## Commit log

2025-01-30 initialization
    Initialize the project repo for every early stage.
2025-02-07 I2C_address_search
    I2C_address_search
2025-02-07 mobile-ESP-BLE-init
    The mobile can connect to ESP32 by APP through BLE, however, the WiFi info and GPS data was not trans yet. Need further development on both ESP32(Arduino) and APP(Flutter). There are several issues with the APP: After connecting to the device, there is no disconnect button designed, which will cause the IoT device to remain connected to the phone unless one of the devices is disconnected. In addition, after selecting a device, the connection button does not display different content according to the connection status of the corresponding device
    [Blink.ino, basic-BLE.ino, main.cpp]
2025-02-09 app update
    This app has better feedback for debugging, however, the function was not fixed yet
    [Advanced-BLE.ino, Multi-Threads.ino]
2025-02-09 update code for calibration and direction finding
2025-02-19 update led guide system, Known Issues: 1. Compass calibration incomplete 2. LED indices and RGB values need adjustment 3. Compass sensor and LED strip must remain stationary relative to each other du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
    [LED_guide_system.ino, lighting_system.ino]
2025-02-24 simple-MQTT
    simple-MQTT two devices publish and then subscribe to each other, only test the uploading function
2025-02-24 Update myConfig.h
    Set up modes for:// #define MODE_JACK // 设备为 Jack 模式
    #define MODE_ROSE // 设备为 Rose 模式
    #define COUPLE_NUM "001"
2025-02-25 main_program_update
    Upload GPS info through MQTT as the start of device is powered. Also test the MQTT send functions are all ready for recall.
2025-02-25 update LED guide system
2025-02-26 main_program update
    Created MQTT topics for reading Status. The status and emotion reset are simply tested right.
    [main_program_GPP.ino, myCompass.h]
2025-03-04 version3
    based on v1, vibration added
    [main_program_GPP_combine_v3.ino, myCompass.h, myLEDandBtns.h]
2025-03-04 v3 update
    v2 was checked good to use, and v3 is the version with the shinning LEDs and regulated vibatrator
2025-03-04 v4
    The bug of press the emotion btn before the start send btn is fixed in v4
    [main_program_GPP_combine_v4.ino, myCompass.h, myLEDandBtns.h]
2025-03-12 LED Ring Update
    LED Ring Update， yellow for happy，after receive message with right dir，show the color imminently and short vibrate
    [main_program_GPP_combine_v4.ino]
2025-04-26 Update enclosure part in README.md
2025-04-26 Create LaserCut
